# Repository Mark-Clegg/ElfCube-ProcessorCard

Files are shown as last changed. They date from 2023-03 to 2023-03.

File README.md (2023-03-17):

# Elf-Cube - Processor card
Simple retro computer based on the 1802 series of processors.

Holds the main CPU, 1 x 32K ROM and 2 x 32K RAM sockets.

After reset, ROM runs from 0x0000 - 0x7FFF and RAM from 0x8000 - 0xFFFF. As soon as an instruction fetch occurs from RAM, the
ROM is replaced with the second RAM chip leaving a full 64K RAM available to user programs.

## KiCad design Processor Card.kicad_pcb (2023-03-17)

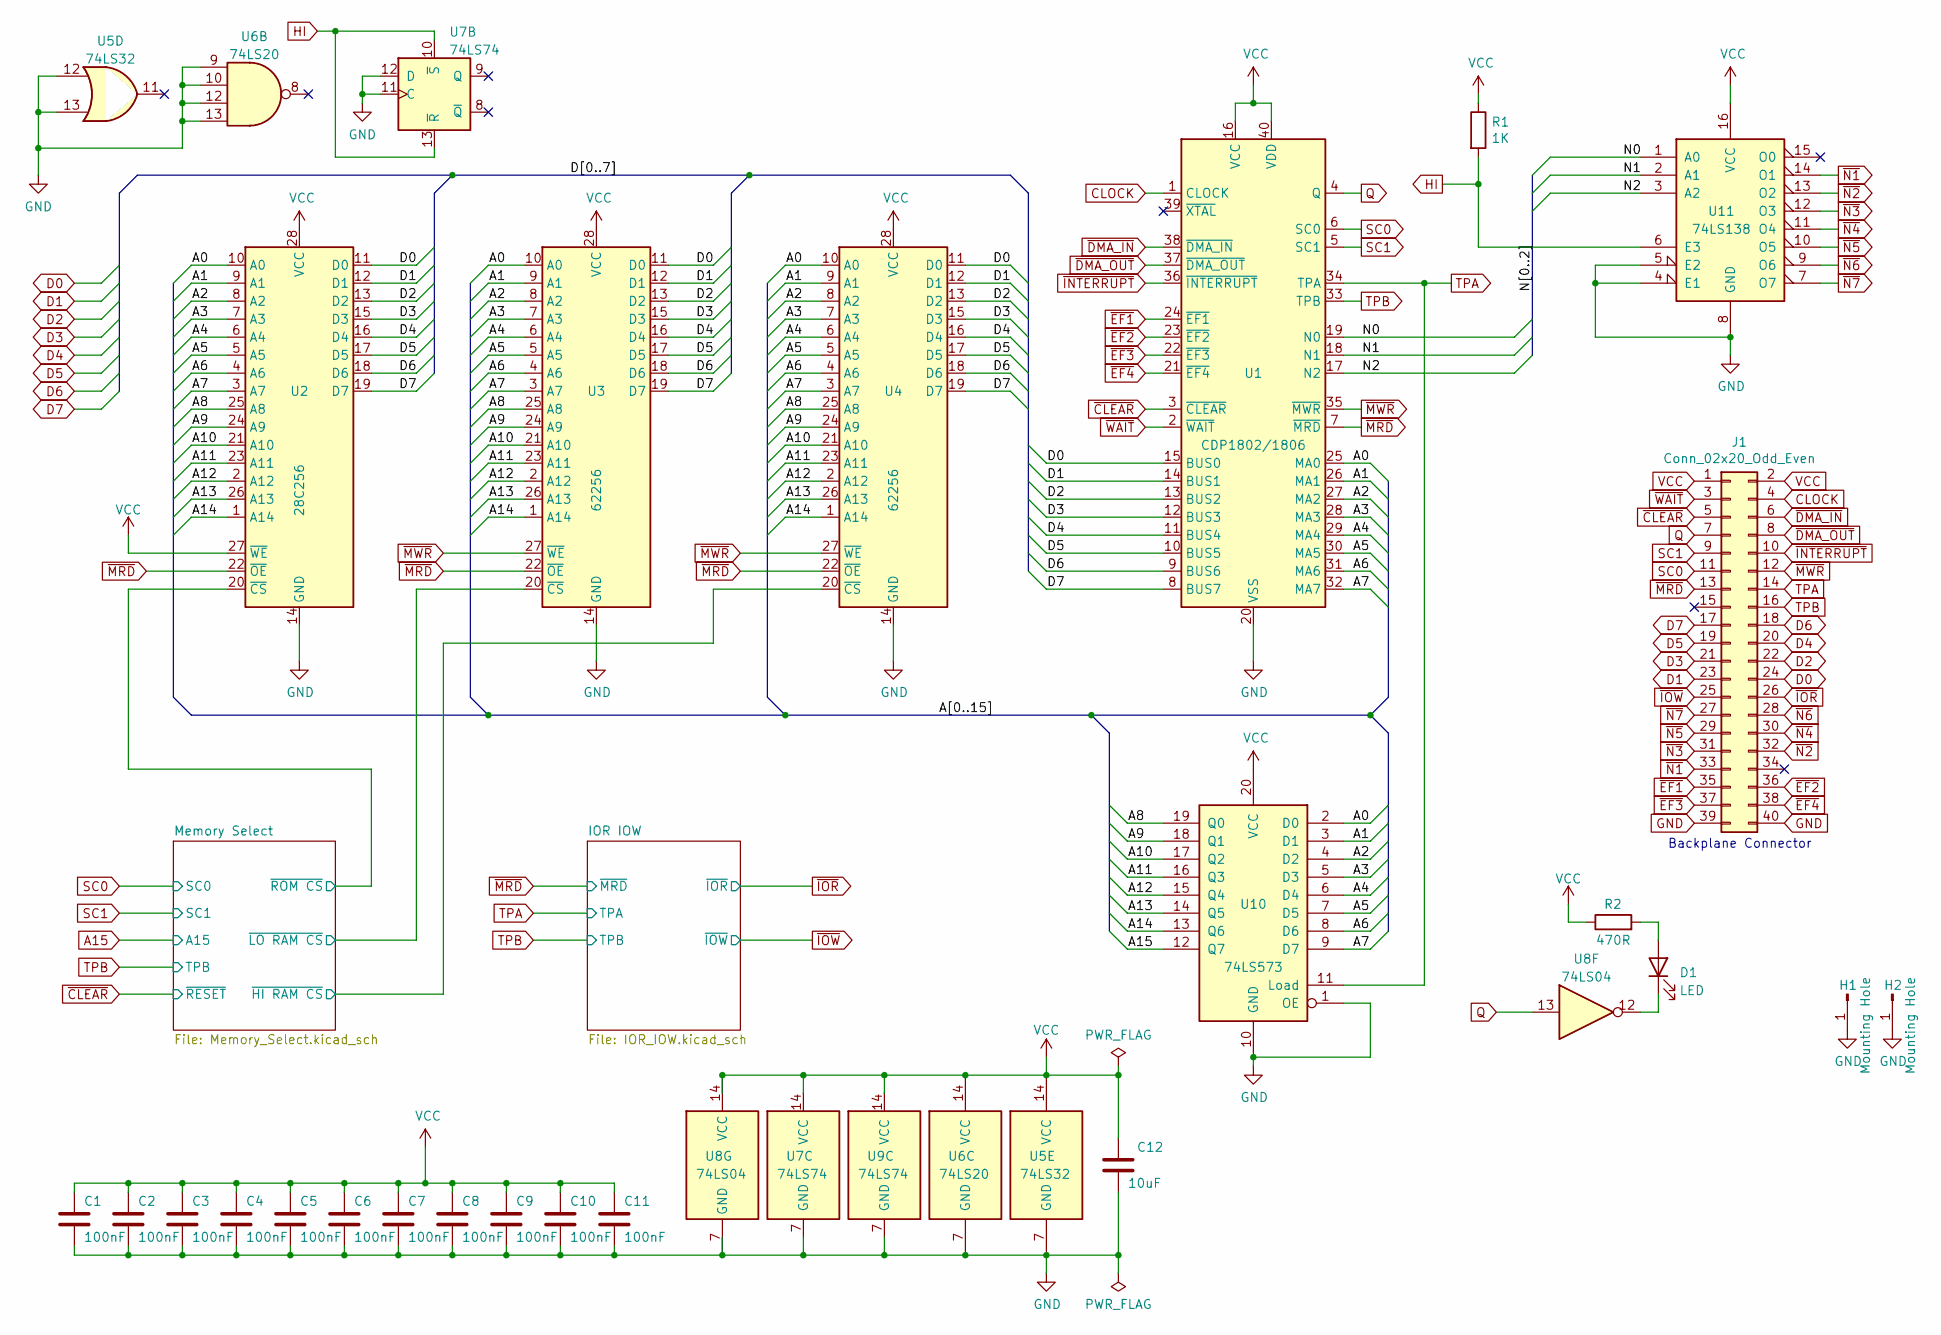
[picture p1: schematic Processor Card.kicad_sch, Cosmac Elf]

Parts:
C1, C2, C3, C4, C5, C6, C7, C8, C9, C10, C11: 100nF; C_Disc_D3.8mm_W2.6mm_P2.50mm
C12: 10uF; CP_Radial_D5.0mm_P2.50mm
D1: LED; LED_D3.0mm_Horizontal_O1.27mm_Z2.0mm
H1, H2: Mounting Hole; MountingHole_3.2mm_M3_Pad_Via
J1: Conn_02x20_Odd_Even; PinHeader_2x20_P2.54mm_Horizontal
R1: 1K; R_Axial_DIN0207_L6.3mm_D2.5mm_P7.62mm_Horizontal
R2: 470R; R_Axial_DIN0207_L6.3mm_D2.5mm_P7.62mm_Horizontal
U1: CDP1802/1806; DIP-40_W15.24mm_Socket
U2: 28C256; DIP-28_W15.24mm_Socket
U3, U4: 62256; DIP-28_W15.24mm_Socket
U5: 74LS32; DIP-14_W7.62mm
U6: 74LS20; DIP-14_W7.62mm
U7, U9: 74LS74; DIP-14_W7.62mm
U8: 74LS04; DIP-14_W7.62mm
U10: 74LS573; DIP-20_W7.62mm
U11: 74LS138; DIP-16_W7.62mm

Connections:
/A0: U1.25 (MA0), U2.10 (A0), U3.10 (A0), U4.10 (A0), U10.2 (D0)
/A1: U1.26 (MA1), U2.9 (A1), U3.9 (A1), U4.9 (A1), U10.3 (D1)
/A2: U1.27 (MA2), U2.8 (A2), U3.8 (A2), U4.8 (A2), U10.4 (D2)
/A3: U1.28 (MA3), U2.7 (A3), U3.7 (A3), U4.7 (A3), U10.5 (D3)
/A4: U1.29 (MA4), U2.6 (A4), U3.6 (A4), U4.6 (A4), U10.6 (D4)
/A5: U1.30 (MA5), U2.5 (A5), U3.5 (A5), U4.5 (A5), U10.7 (D5)
/A6: U1.31 (MA6), U2.4 (A6), U3.4 (A6), U4.4 (A6), U10.8 (D6)
/A7: U1.32 (MA7), U2.3 (A7), U3.3 (A7), U4.3 (A7), U10.9 (D7)
/A8: U2.25 (A8), U3.25 (A8), U4.25 (A8), U10.19 (Q0)
/A9: U2.24 (A9), U3.24 (A9), U4.24 (A9), U10.18 (Q1)
/A10: U2.21 (A10), U3.21 (A10), U4.21 (A10), U10.17 (Q2)
/A11: U2.23 (A11), U3.23 (A11), U4.23 (A11), U10.16 (Q3)
/A12: U2.2 (A12), U3.2 (A12), U4.2 (A12), U10.15 (Q4)
/A13: U2.26 (A13), U3.26 (A13), U4.26 (A13), U10.14 (Q5)
/A14: U2.1 (A14), U3.1 (A14), U4.1 (A14), U10.13 (Q6)
/Memory Select/~HI RAM CS: U4.20 (~CS); also elsewhere on the board
/Memory Select/~LO RAM CS: U3.20 (~CS); also elsewhere on the board
/Memory Select/~ROM CS: U2.20 (~CS); also elsewhere on the board
/N0: U1.19 (N0), U11.1 (A0)
/N1: U1.18 (N1), U11.2 (A1)
/N2: U1.17 (N2), U11.3 (A2)
A15: U10.12 (Q7); also elsewhere on the board
CLOCK: J1.4, U1.1 (CLOCK)
D0: J1.24, U1.15 (BUS0), U2.11 (D0), U3.11 (D0), U4.11 (D0)
D1: J1.23, U1.14 (BUS1), U2.12 (D1), U3.12 (D1), U4.12 (D1)
D2: J1.22, U1.13 (BUS2), U2.13 (D2), U3.13 (D2), U4.13 (D2)
D3: J1.21, U1.12 (BUS3), U2.15 (D3), U3.15 (D3), U4.15 (D3)
D4: J1.20, U1.11 (BUS4), U2.16 (D4), U3.16 (D4), U4.16 (D4)
D5: J1.19, U1.10 (BUS5), U2.17 (D5), U3.17 (D5), U4.17 (D5)
D6: J1.18, U1.9 (BUS6), U2.18 (D6), U3.18 (D6), U4.18 (D6)
D7: J1.17, U1.8 (BUS7), U2.19 (D7), U3.19 (D7), U4.19 (D7)
GND: C1.2, C2.2, C3.2, C4.2, C5.2, C6.2, C7.2, C8.2, C9.2, C10.2, C11.2, C12.2, H1.1, H2.1, J1.39, J1.40, U1.20 (VSS), U2.14 (GND), U3.14 (GND), U4.14 (GND), U5.7 (GND), U5.12, U5.13, U6.7 (GND), U6.9, U6.10, U6.12, U6.13, U7.7 (GND), U7.11 (C), U7.12 (D), U8.7 (GND), U9.7 (GND), U10.1 (OE), U10.10 (GND), U11.4 (E1), U11.5 (E2), U11.8 (GND); also elsewhere on the board
HI: R1.2, U7.10 (~S), U7.13 (~R), U11.6 (E3); also elsewhere on the board
unnamed: D1.1 (K), U8.12
unnamed: D1.2 (A), R2.2
Q: J1.7, U1.4 (Q), U8.13
SC0: J1.11, U1.6 (SC0); also elsewhere on the board
SC1: J1.9, U1.5 (SC1); also elsewhere on the board
TPA: J1.14, U1.34 (TPA), U10.11 (Load); also elsewhere on the board
TPB: J1.16, U1.33 (TPB); also elsewhere on the board
VCC: C1.1, C2.1, C3.1, C4.1, C5.1, C6.1, C7.1, C8.1, C9.1, C10.1, C11.1, C12.1, J1.1, J1.2, R1.1, R2.1, U1.16 (VCC), U1.40 (VDD), U2.27 (~WE), U2.28 (VCC), U3.28 (VCC), U4.28 (VCC), U5.14 (VCC), U6.14 (VCC), U7.14 (VCC), U8.14 (VCC), U9.14 (VCC), U10.20 (VCC), U11.16 (VCC)
~CLEAR: J1.5, U1.3 (~CLEAR); also elsewhere on the board
~DMA_IN: J1.6, U1.38 (~DMA_IN)
~DMA_OUT: J1.8, U1.37 (~DMA_OUT)
~EF1: J1.35, U1.24 (~EF1)
~EF2: J1.36, U1.23 (~EF2)
~EF3: J1.37, U1.22 (~EF3)
~EF4: J1.38, U1.21 (~EF4)
~INTERRUPT: J1.10, U1.36 (~INTERRUPT)
~IOR: J1.26; also elsewhere on the board
~IOW: J1.25; also elsewhere on the board
~MRD: J1.13, U1.7 (~MRD), U2.22 (~OE), U3.22 (~OE), U4.22 (~OE); also elsewhere on the board
~MWR: J1.12, U1.35 (~MWR), U3.27 (~WE), U4.27 (~WE)
~N1: J1.33, U11.14 (O1)
~N2: J1.32, U11.13 (O2)
~N3: J1.31, U11.12 (O3)
~N4: J1.30, U11.11 (O4)
~N5: J1.29, U11.10 (O5)
~N6: J1.28, U11.9 (O6)
~N7: J1.27, U11.7 (O7)
~WAIT: J1.3, U1.2 (~WAIT)

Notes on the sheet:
Backplane Connector

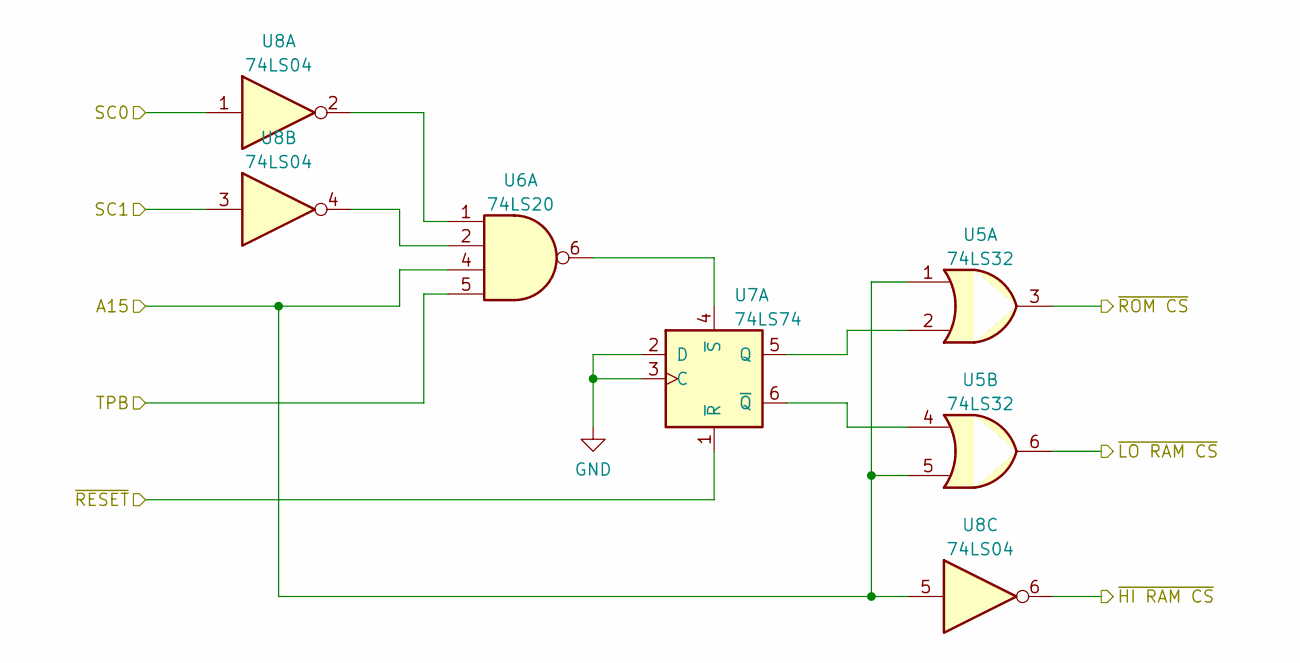
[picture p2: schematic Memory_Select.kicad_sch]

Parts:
U5: 74LS32; DIP-14_W7.62mm
U6: 74LS20; DIP-14_W7.62mm
U7: 74LS74; DIP-14_W7.62mm
U8: 74LS04; DIP-14_W7.62mm

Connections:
/Memory Select/~HI RAM CS: U8.6; also elsewhere on the board
/Memory Select/~LO RAM CS: U5.6; also elsewhere on the board
/Memory Select/~ROM CS: U5.3; also elsewhere on the board
A15: U5.1, U5.5, U6.4, U8.5; also elsewhere on the board
GND: U7.2 (D), U7.3 (C); also elsewhere on the board
unnamed: U5.2, U7.5 (Q)
unnamed: U5.4, U7.6 (~Q)
unnamed: U6.1, U8.2
unnamed: U6.2, U8.4
unnamed: U6.6, U7.4 (~S)
SC0: U8.1; also elsewhere on the board
SC1: U8.3; also elsewhere on the board
TPB: U6.5; also elsewhere on the board
~CLEAR: U7.1 (~R); also elsewhere on the board

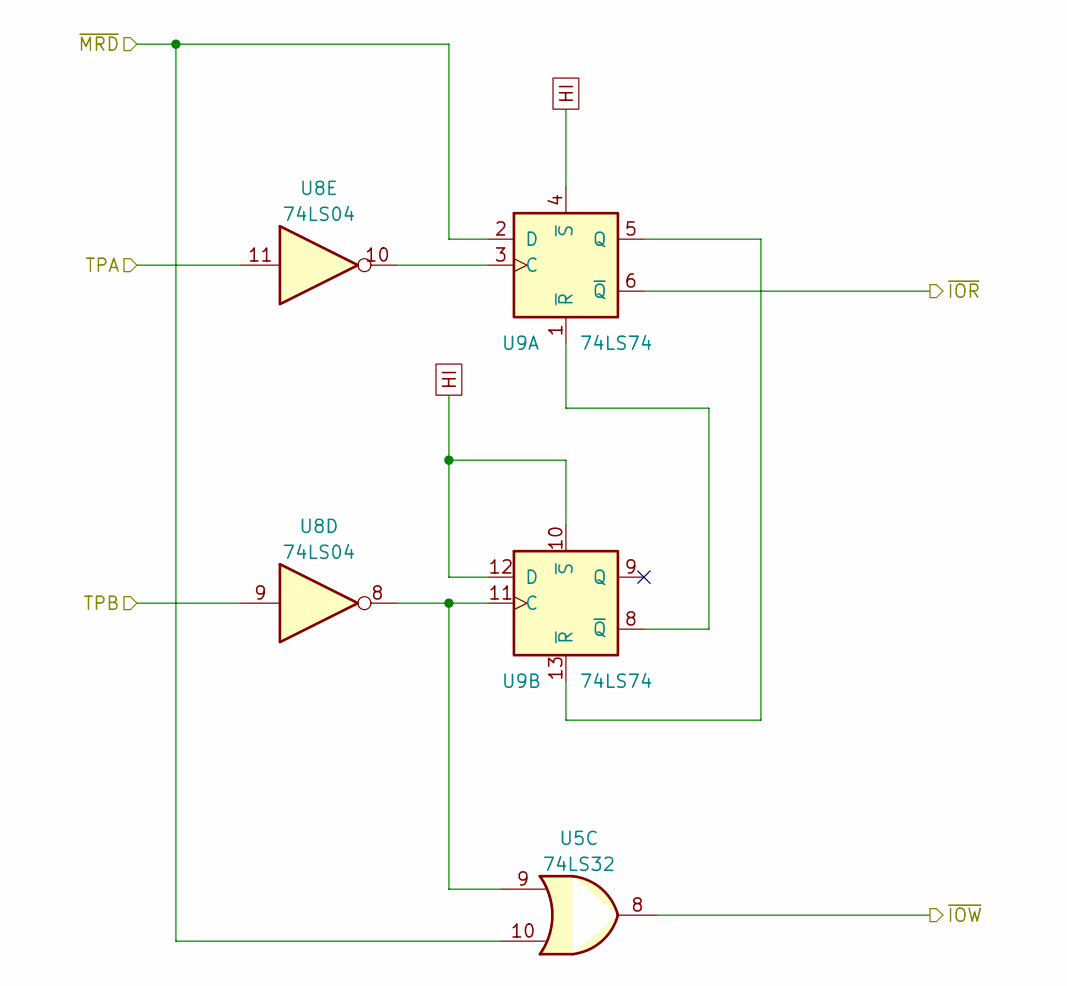
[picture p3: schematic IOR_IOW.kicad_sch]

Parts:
U5: 74LS32; DIP-14_W7.62mm
U8: 74LS04; DIP-14_W7.62mm
U9: 74LS74; DIP-14_W7.62mm

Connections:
HI: U9.4 (~S), U9.10 (~S), U9.12 (D); also elsewhere on the board
unnamed: U5.9, U8.8, U9.11 (C)
unnamed: U8.10, U9.3 (C)
unnamed: U9.1 (~R), U9.8 (~Q)
unnamed: U9.5 (Q), U9.13 (~R)
TPA: U8.11; also elsewhere on the board
TPB: U8.9; also elsewhere on the board
~IOR: U9.6 (~Q); also elsewhere on the board
~IOW: U5.8; also elsewhere on the board
~MRD: U5.10, U9.2 (D); also elsewhere on the board

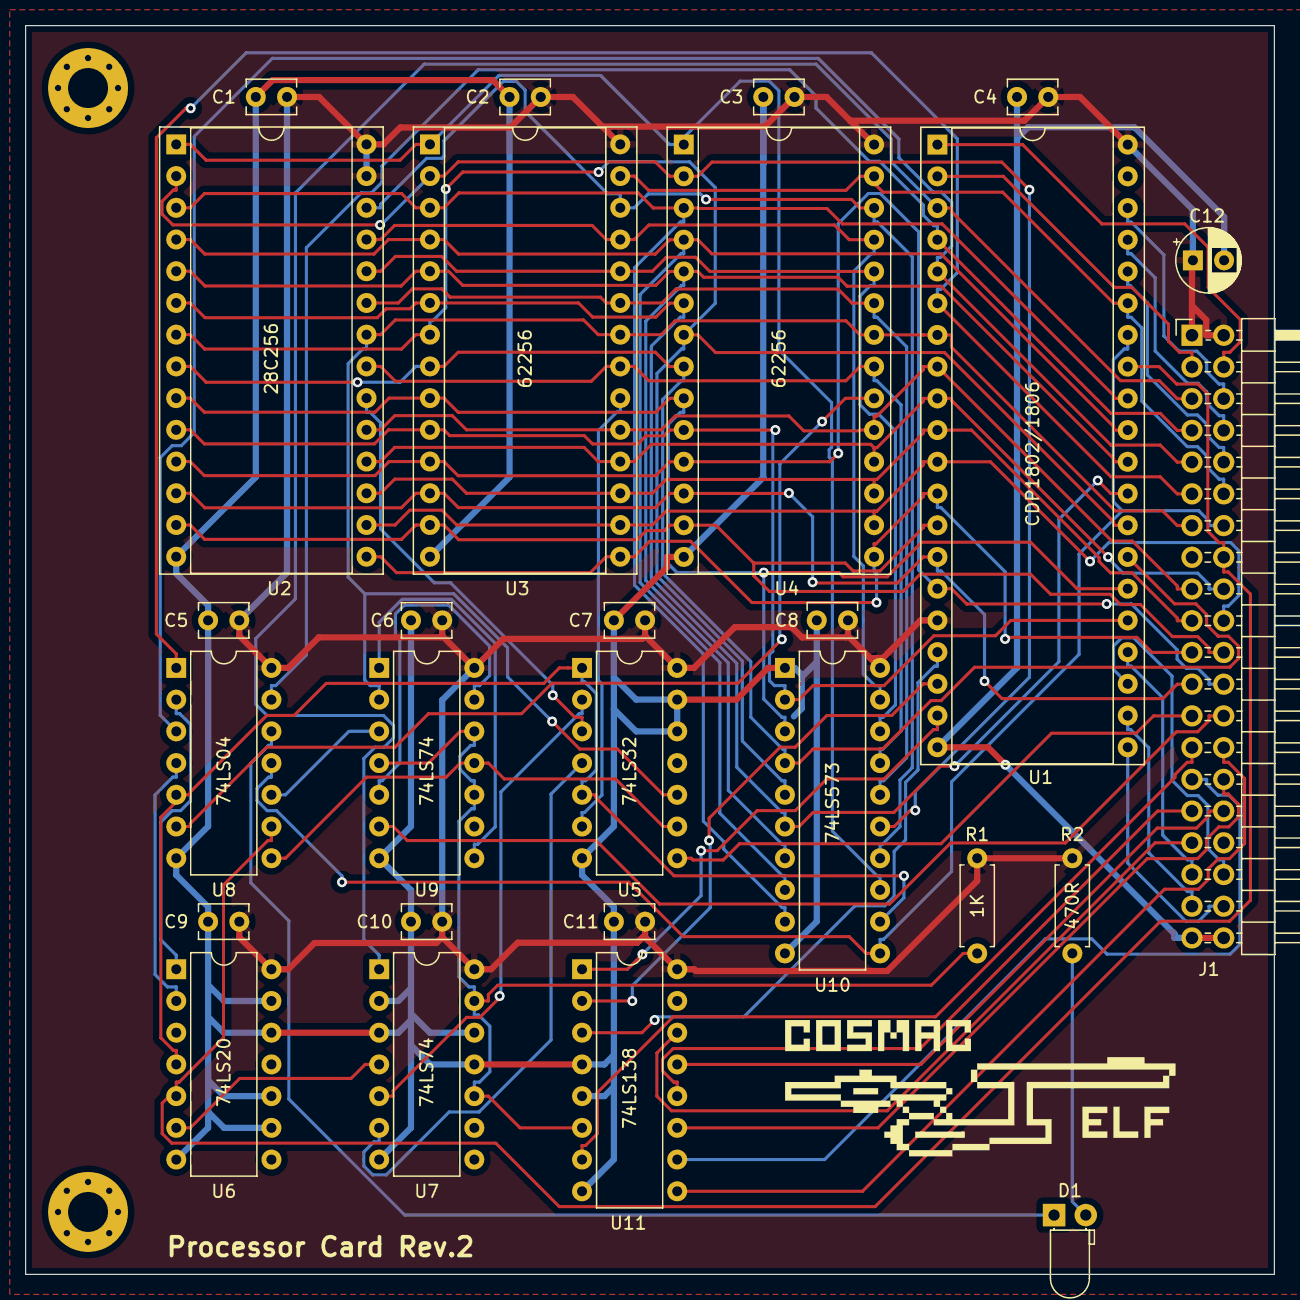
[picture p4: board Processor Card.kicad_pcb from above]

Board: 2 copper layers, 100.0 x 100.0 mm, 29 parts (0 on the bottom side), 70 nets.

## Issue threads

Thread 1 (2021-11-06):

Timing issue with I/O Decode in Rev1.0 board

Mark-Clegg, 2021-11-06:
There is a timing issue generating IOR and IOW, causing both to be low at 4MHz under load.

Mark-Clegg, 2021-11-06:
Resolved by using one of the spare LS32 gates to delay TPA slightly when clocking the LS73 IOR generator.
On Rev1.0 boards this requires cutting the traces to and between pins 4&5 on U1, and the trace between U7 pin 11 and U4 pin 5.
Wire links can then be made from:
U7 pin 11 -> U1 pin 4
U1 pin 5 -> U1 pin 7
U1 pin 6 -> U4 pin 5

Mark-Clegg, 2021-11-23:
Turns out this doesn't quite resolve the issue.
The second spare LS32 gate needs adding into the TPA delay
The traces to pins 1,2 and 3 need cutting, and the wire link on pin 6 moving to pin3
Then new links as follows:
U1 pin 6 -> U1 pins 1 & 2
Bottom of R3 -> U4 pin 14

Closed 2021-11-06.

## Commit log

2021-11-06 Rev 1.0
    [Processor Card.kicad_pcb, Processor Card.sch]
2021-11-06 Added Gate Delay to IO Decode
    [Processor Card.kicad_pcb, Processor Card.sch]
2023-02-21 Revision 2
    [IOR_IOW.kicad_sch, Memory_Select.kicad_sch, Processor Card.kicad_pcb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]
2023-03-02 Fix PCB / Schematic mismatch
    [Processor Card.kicad_pcb]
2023-03-03 Finalised layout
    [Processor Card.kicad_pcb]
2023-03-17 Rev 2
    [IOR_IOW.kicad_sch, Memory_Select.kicad_sch, Processor Card.kicad_pcb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]
